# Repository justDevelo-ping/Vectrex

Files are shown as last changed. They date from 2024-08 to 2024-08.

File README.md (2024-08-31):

# Vectrex
 In here, we will find all the work i've done to make more customization and reproduction of the vectrex arcade system available.

Kailh LP Modern Vectrex Controller © 2024 by Francis Olivier Houle is licensed under CC BY-NC 4.0. To view a copy of this license, visit https://creativecommons.org/licenses/by-nc/4.0/

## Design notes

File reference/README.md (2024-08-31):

# Vectrex Reference	
 In here, we will find all the work i've refered to to produce my CAD file and my variation.

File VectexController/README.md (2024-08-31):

# Vectrex Controller v1.0
 This is the v0.1 of my controller including le PCB.
 
 - Possible Issues :
	- The joystick might be too big and prevent closing the remote inside he vectrex like the original intended
	
The controller is builded by staying fidele to the BOM of the original vectrex controller with part still in production. With the original schematic, the controller joystick is planned to work with 2.4v wich make it hit all the boxes on the test cartridge. a higher voltage Schemetic will be made later.

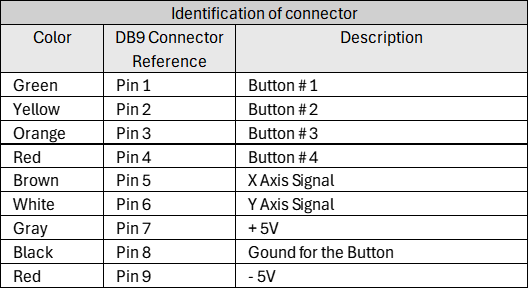
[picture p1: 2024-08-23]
reference/ConnectionTable.png

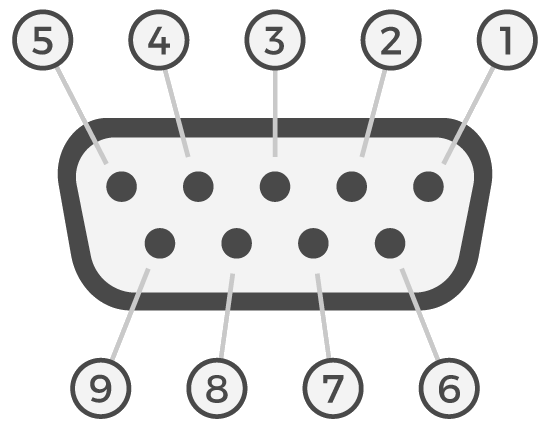
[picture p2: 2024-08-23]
reference/DB9_Female.png

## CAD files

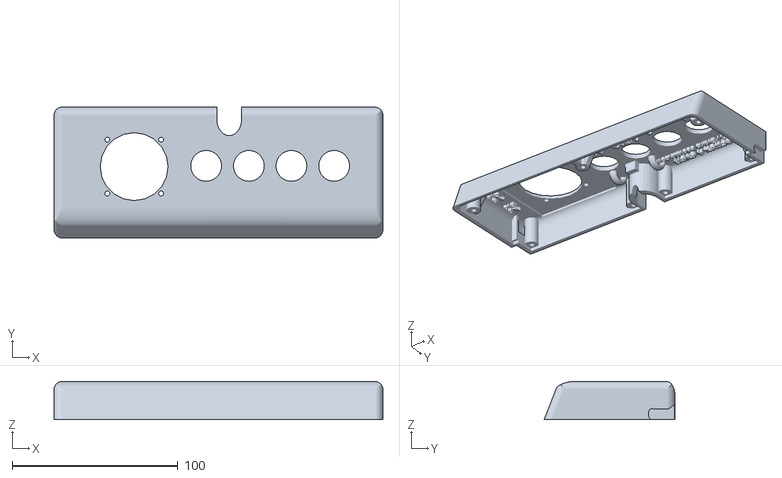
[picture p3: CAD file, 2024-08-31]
reference/3d model/Coolate-Pro/Vectrex_Controller_PRO_18mm.stl
198.7 x 79.0 x 23.0

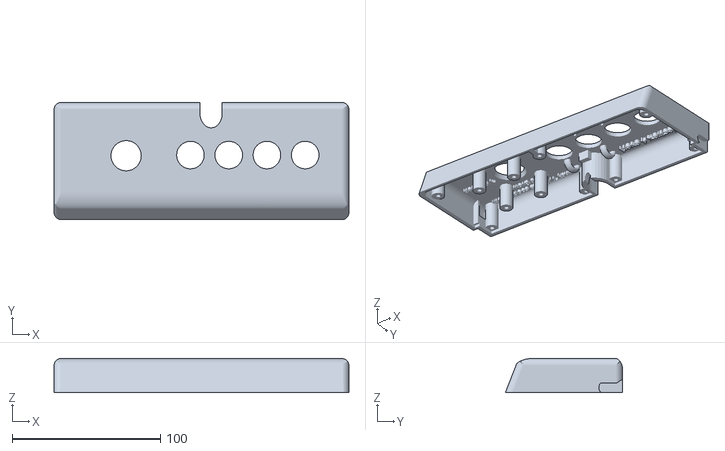
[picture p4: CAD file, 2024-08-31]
reference/3d model/Coolate/VectrexControllerTopAdaFruitMount18mm.stl
198.7 x 79.0 x 23.0

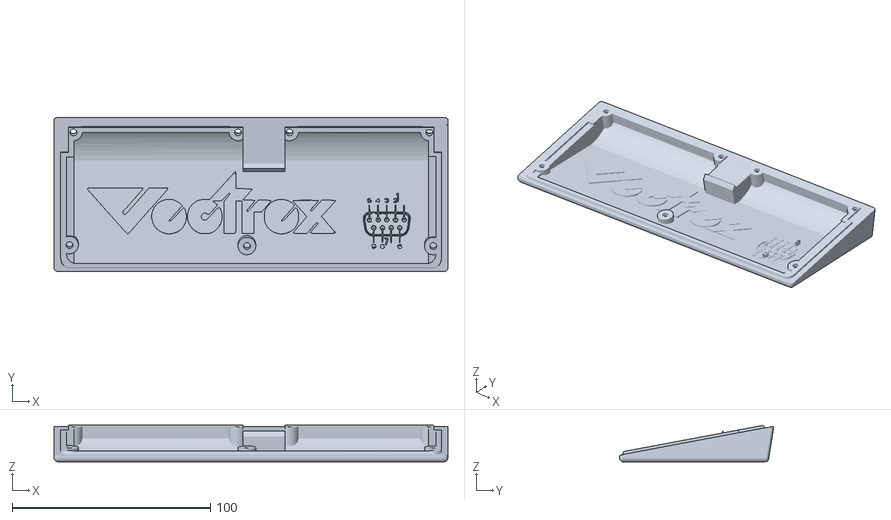
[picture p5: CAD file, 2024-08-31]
reference/3d model/Cyllenius/vectrex-controller-bottom.stl
198.7 x 77.8 x 18.4

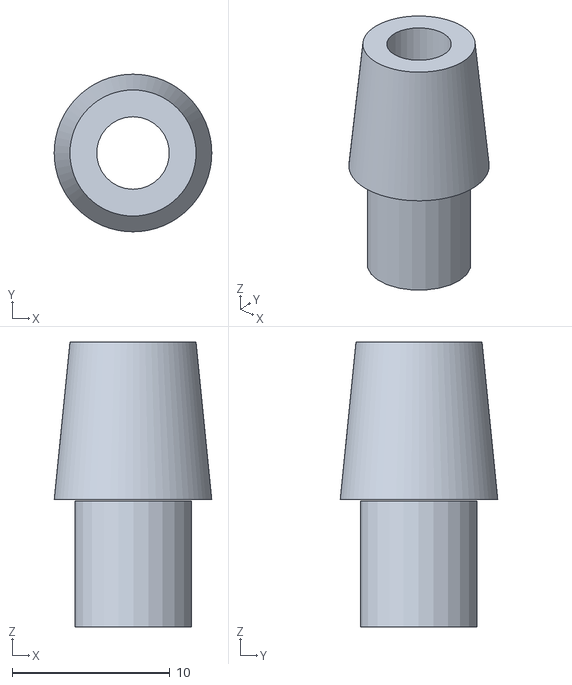
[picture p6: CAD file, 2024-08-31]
reference/3d model/Vectrex_Plug_Strain_Relief.stl
10.0 x 10.0 x 18.1

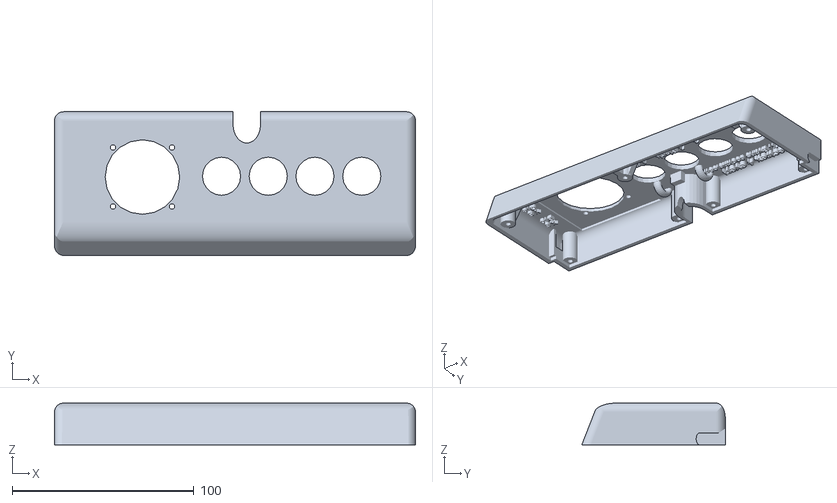
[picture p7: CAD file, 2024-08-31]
reference/3d model/Coolate-Pro/Vectrex_Controller_PRO_20mm.stl
198.7 x 79.0 x 23.0

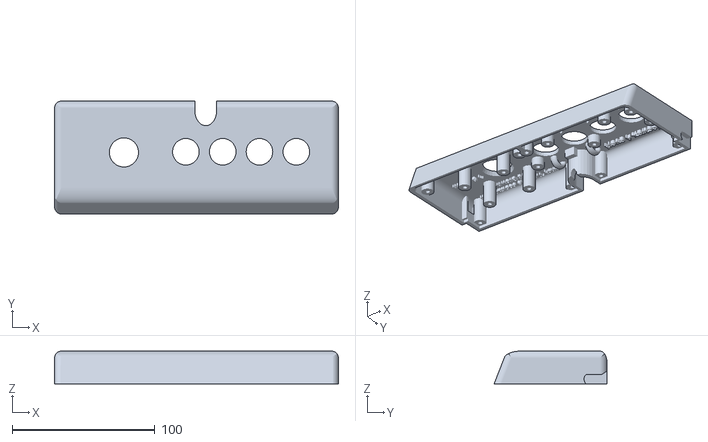
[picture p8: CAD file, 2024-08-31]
reference/3d model/Coolate/VectrexControllerTop.stl
198.7 x 79.0 x 23.0

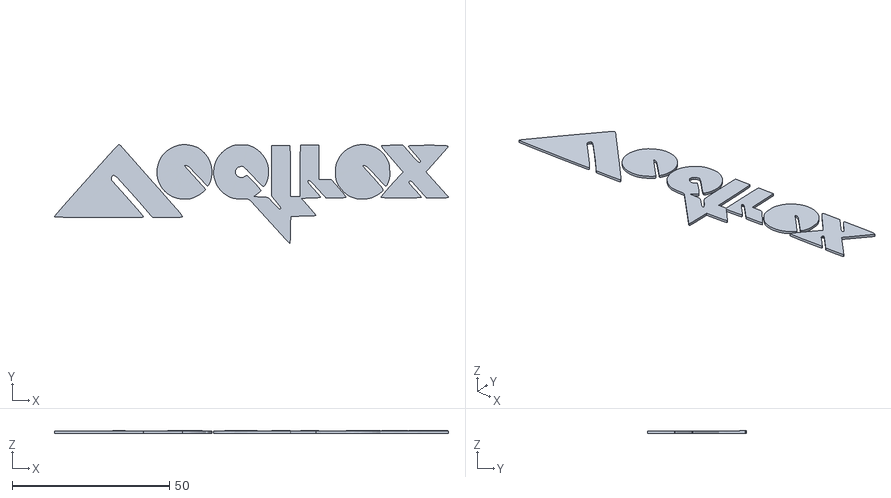
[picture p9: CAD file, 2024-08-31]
reference/3d model/Cyllenius/vectrex-controller-bottom-decoration.stl
125.3 x 31.5 x 0.804

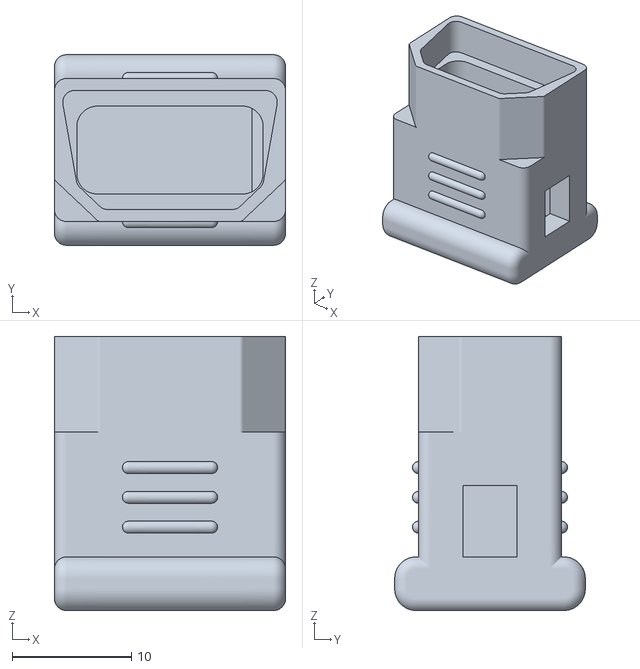
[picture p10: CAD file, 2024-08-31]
reference/3d model/Vectrex_Joystick_Plug.stl
19.4 x 16.0 x 23.0

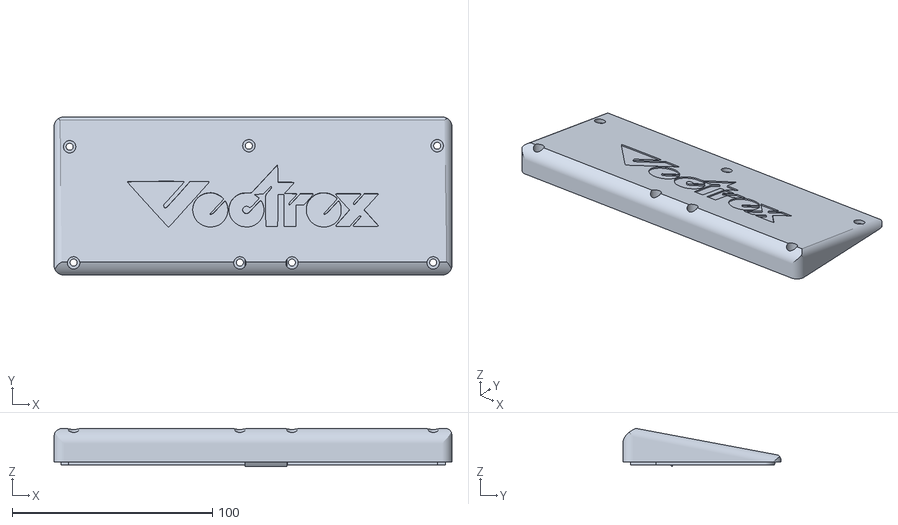
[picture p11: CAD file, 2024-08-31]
reference/3d model/Coolate-Pro/Vectrex_Bottom_NEW.stl
198.7 x 79.0 x 19.1

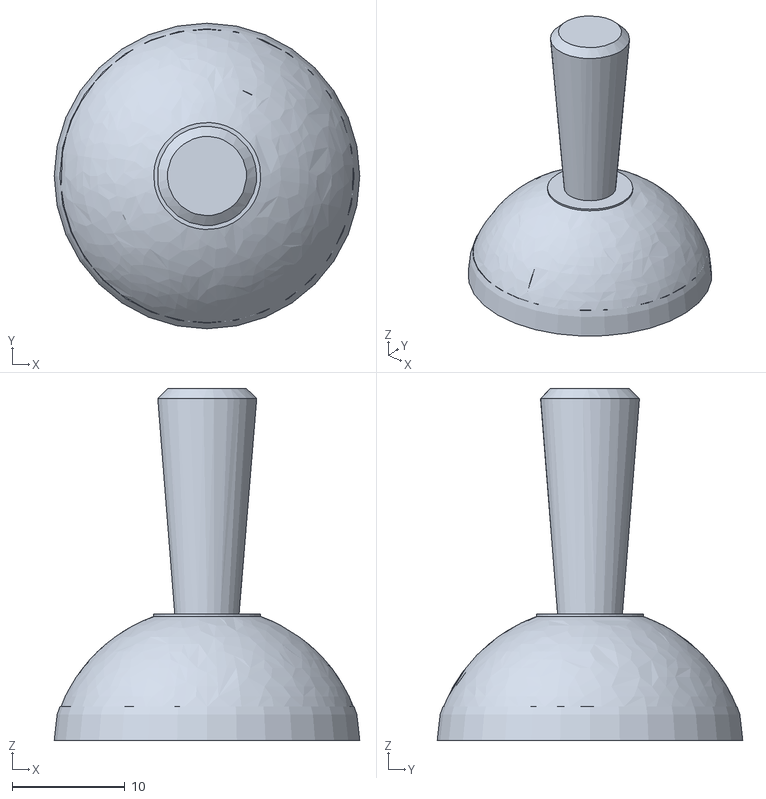
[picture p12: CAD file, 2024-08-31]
reference/3d model/Coolate/VectrexControllerJoystick.stl
27.1 x 27.1 x 31.2

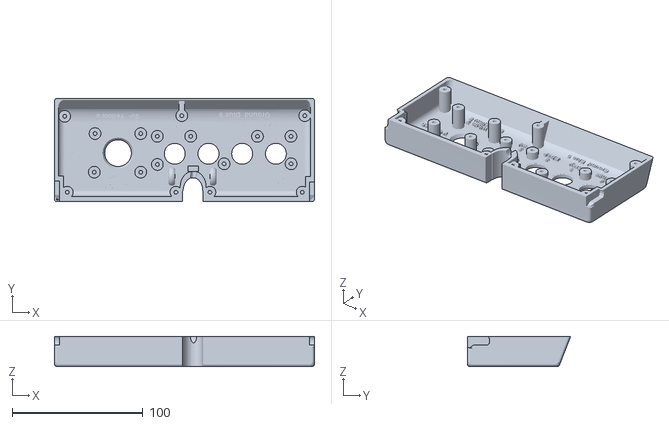
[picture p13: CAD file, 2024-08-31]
reference/3d model/Cyllenius/vectrex-controller-top.stl
198.7 x 79.0 x 23.0

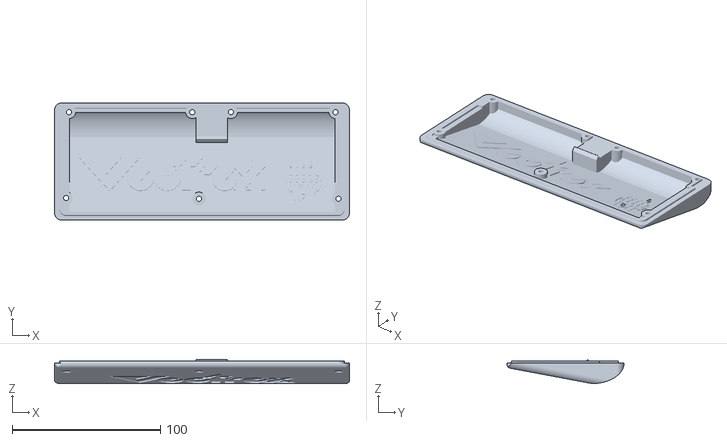
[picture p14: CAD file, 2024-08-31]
reference/3d model/Coolate/VectrexControllerBottom.stl
198.7 x 79.0 x 16.3

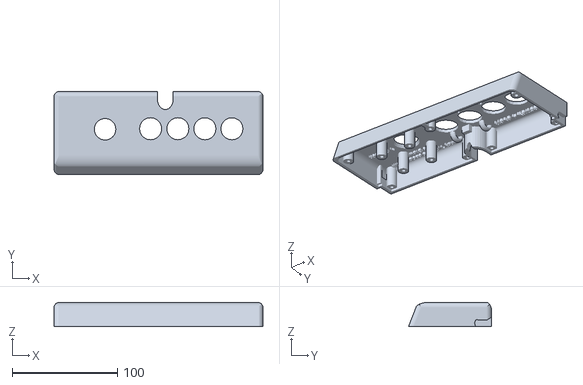
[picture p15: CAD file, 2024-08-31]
reference/3d model/Coolate/VectrexControllerTopAdaFruitMount20mm.stl
198.7 x 79.0 x 23.0

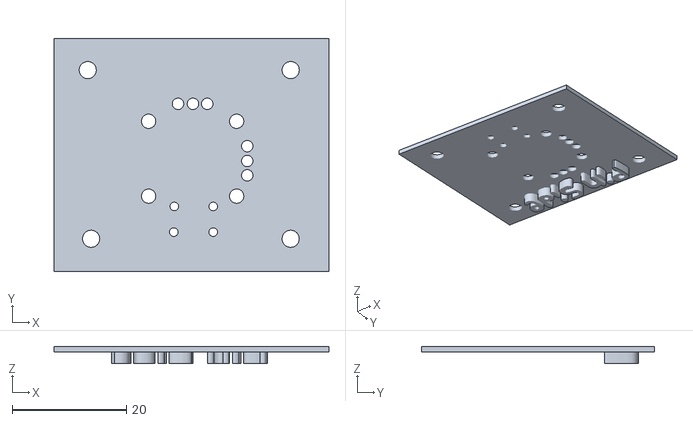
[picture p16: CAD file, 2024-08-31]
reference/3d model/Coolate/VectrexControllerPCBTemp.stl
48.1 x 40.7 x 3.00

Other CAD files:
reference/3d model/Coolate/VectrexController20mmButtons.stl
reference/3d model/Coolate/VectrexControllerJoystickWithNotch.stl

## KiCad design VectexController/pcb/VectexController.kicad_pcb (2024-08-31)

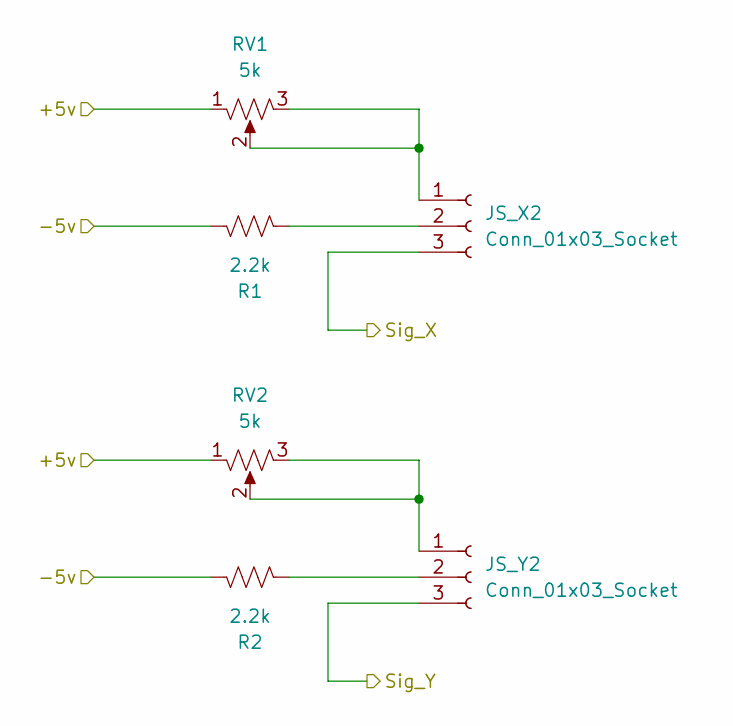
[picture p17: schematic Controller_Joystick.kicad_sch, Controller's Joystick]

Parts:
JS_X2: Conn_01x03_Socket; JST_XH_B3B-XH-A_1x03_P2.50mm_Vertical
JS_Y2: Conn_01x03_Socket; JST_XH_B3B-XH-A_1x03_P2.50mm_Vertical
R1, R2: 2.2k; R_Axial_DIN0207_L6.3mm_D2.5mm_P10.16mm_Horizontal
RV1, RV2: 5k; Potentiometer_Bourns_3296W_Vertical

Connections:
/Controller_Joystick/+5v: RV1.1, RV2.1; also elsewhere on the board
/Controller_Joystick/-5v: R1.1, R2.1; also elsewhere on the board
/Controller_Joystick/Sig_X: JS_X2.3; also elsewhere on the board
/Controller_Joystick/Sig_Y: JS_Y2.3; also elsewhere on the board
unnamed: JS_X2.1, RV1.2, RV1.3
unnamed: JS_X2.2, R1.2
unnamed: JS_Y2.1, RV2.2, RV2.3
unnamed: JS_Y2.2, R2.2

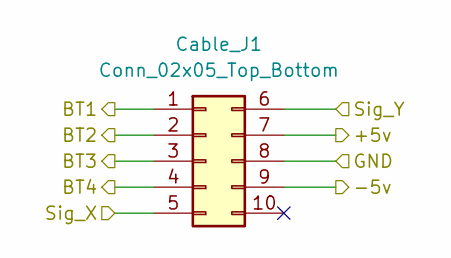
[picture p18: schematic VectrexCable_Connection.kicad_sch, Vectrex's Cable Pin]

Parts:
Cable_J1: Conn_02x05_Top_Bottom; PinHeader_2x05_P2.54mm_Horizontal

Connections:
/Controller_Button/BT1: Cable_J1.1; also elsewhere on the board
/Controller_Button/BT2: Cable_J1.2; also elsewhere on the board
/Controller_Button/BT3: Cable_J1.3; also elsewhere on the board
/Controller_Button/BT4: Cable_J1.4; also elsewhere on the board
/Controller_Button/GND: Cable_J1.8; also elsewhere on the board
/Controller_Joystick/+5v: Cable_J1.7; also elsewhere on the board
/Controller_Joystick/-5v: Cable_J1.9; also elsewhere on the board
/Controller_Joystick/Sig_X: Cable_J1.5; also elsewhere on the board
/Controller_Joystick/Sig_Y: Cable_J1.6; also elsewhere on the board

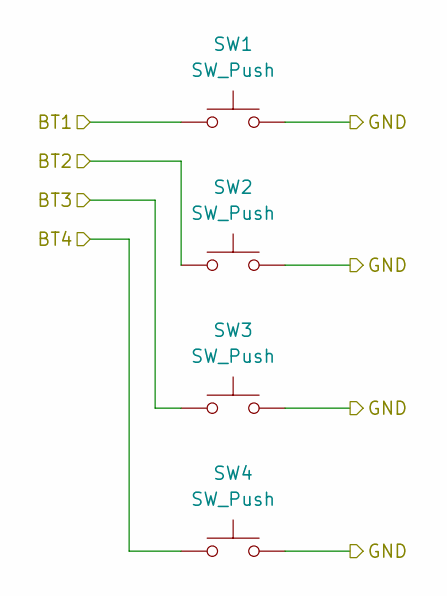
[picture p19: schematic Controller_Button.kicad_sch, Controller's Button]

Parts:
SW1, SW2, SW3, SW4: SW_Push; Kailh_socket_PG1350_optional

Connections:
/Controller_Button/BT1: SW1.1; also elsewhere on the board
/Controller_Button/BT2: SW2.1; also elsewhere on the board
/Controller_Button/BT3: SW3.1; also elsewhere on the board
/Controller_Button/BT4: SW4.1; also elsewhere on the board
/Controller_Button/GND: SW1.2, SW2.2, SW3.2, SW4.2; also elsewhere on the board

Board: 2 copper layers, 11 parts (0 on the bottom side), 13 nets, no tracks yet.

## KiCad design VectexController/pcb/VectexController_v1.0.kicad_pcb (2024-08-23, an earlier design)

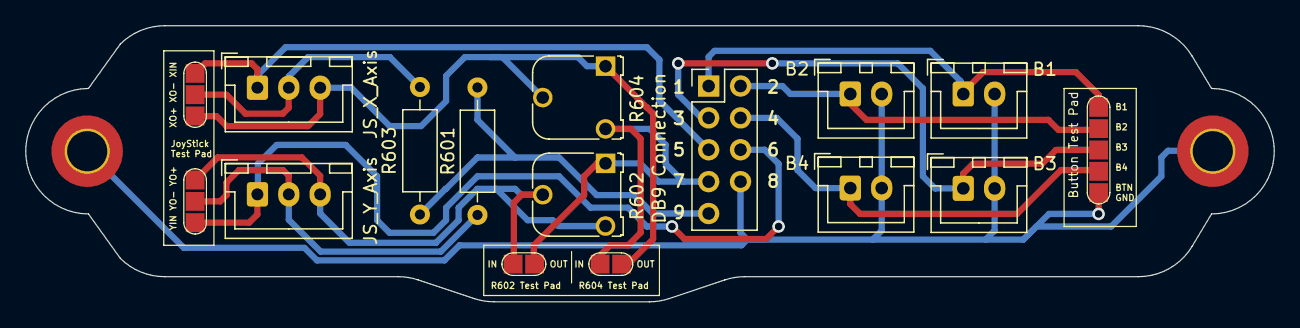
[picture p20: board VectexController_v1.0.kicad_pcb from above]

Board: 2 copper layers, 99.5 x 22.0 mm, 18 parts (0 on the bottom side), 13 nets.

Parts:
B1: SW_Push1; JST_XH_B2B-XH-A_1x02_P2.50mm_Vertical
B2: SW_Push2; JST_XH_B2B-XH-A_1x02_P2.50mm_Vertical
B3: SW_Push3; JST_XH_B2B-XH-A_1x02_P2.50mm_Vertical
B4: SW_Push4; JST_XH_B2B-XH-A_1x02_P2.50mm_Vertical
Button Test Pad : TestPoint_Pad_1.5x1.5mm_x5
DB9 Connection: Conn_2Rows-09Pins; PinHeader_2x05_P2.54mm_Vertical
IN           OUT: TestPoint_Pad_1.5x1.5mm_x2
IN           OUT#2: TestPoint_Pad_1.5x1.5mm_x2
JS_X_Axis: 3Pins; JST_XH_B3B-XH-A_1x03_P2.50mm_Vertical
JS_Y_Axis: 3Pins; JST_XH_B3B-XH-A_1x03_P2.50mm_Vertical
MntHole1, MntHole2: MountingHole_3.2mm_M3_ISO7380_Pad_TopOnly
R601, R603: 4.7k; R_Axial_DIN0207_L6.3mm_D2.5mm_P10.16mm_Horizontal
R602, R604: 10k; Potentiometer_Runtron_RM-065_Vertical
XO+ XO- XIN: TestPoint_Pad_1.5x1.5mm_x3
YIN YO- YO+: TestPoint_Pad_1.5x1.5mm_x3

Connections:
unnamed: B1.1, Button Test Pad.1, DB9 Connection.1
unnamed: B2.1, Button Test Pad.2, DB9 Connection.2
unnamed: B3.1, Button Test Pad.3, DB9 Connection.3
unnamed: B4.1, Button Test Pad.4, DB9 Connection.4
unnamed: DB9 Connection.5, JS_X_Axis.1, XO+ XO- XIN.1
unnamed: DB9 Connection.6, JS_Y_Axis.1, YIN YO- YO+.1
unnamed: DB9 Connection.7, IN OUT.2, IN OUT#2.2, R602.1, R604.3
unnamed: B1.2, B2.2, B3.2, B4.2, Button Test Pad.5, DB9 Connection.8, MntHole1.1, MntHole2.1
unnamed: DB9 Connection.9, R601.2, R603.2
unnamed: JS_X_Axis.2, R603.1, XO+ XO- XIN.2
unnamed: IN OUT.1, JS_X_Axis.3, R604.1, R604.2, XO+ XO- XIN.3
unnamed: JS_Y_Axis.2, R601.1, YIN YO- YO+.2
unnamed: IN OUT#2.1, JS_Y_Axis.3, R602.2, R602.3, YIN YO- YO+.3
